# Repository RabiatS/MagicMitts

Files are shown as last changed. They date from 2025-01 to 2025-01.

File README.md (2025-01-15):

<!--
Name of your team's  project
-->
# Magic Mitts - Electromagnetic Haptic gloves for realistic VR interactions

<!--
List all of the members who developed the project and
link to each members respective GitHub profile
-->
Developed by: 
- [Rabiat Sadiq](https://github.com/rabiats) - `Computer Engineer / CS` - `University of Texas at San Antonio`
- [John Navarro ](https://github.com/rabiats) -`Electrical Engineer` - `University of Texas at San Antonio`
- [Juan Casillas](https://github.com/rabiats) - `Computer Engineer` - `University of Texas at San Antonio`
- [Blake Novosad](https://github.com/rabiats) - `Electrical Engineer` - `University of Texas at San Antonio`

## Description
<!--
Give a short description on what your project accomplishes and what tools is uses. In addition, you can drop screenshots directly into your README file to add them to your README. Take these from your presentations.
-->
The Smart VR Glove is an affordable innovation in virtual reality technology that offers users an immersive and realistic experience across standard VR systems.
It utilizes a novel electromagnetic braking system and haptic actuators to provide precise tactile feedback, simulating the sensation of touch and grasp in the virtual world. 
Enhanced by our own self-developed hardware driver, the glove’s flex-sensitive resistors offer superior finger-tracking accuracy.
This wireless, rechargeable battery-powered glove is designed to provide VR users with a more natural VR experience, setting a new benchmark for affordability, compatibility, and interactivity in virtual environments.



## Need for product 
Current virtual reality (VR) and augmented reality (AR) are
currently devoid of an affordable, immersive accessory that offers
haptic feedback and finger pullback functionality, leading to less
engaging user experience marked by inadequate dexterity and
prevalent compatibility issues. The few comprehensive solutions
available, like those from HaptX, command prices upwards of
$4,000, placing them beyond the reach of a broader audience.
This significant cost barrier impedes the universal development
and adoption of deeply immersive and personalized VR/AR
experiences



HatpX Glove



Air Compressor Backpack

## Flow charts
Hardware Flowchart



Software Flowchart



## Features
-  Electromagnetic braking system for simulated grasping resistance
- Integrated motion sensors for accurate hand/finger tracking
- Vibrating Actuators at fingertips for touch feedback
- Seamless connectivity with standard VR platforms
- Lightweight and portable design

## PCB Built from scratch

- Dual Rechargeable Battery System
- USB-C Port Power Compatibility
- Integrated Sensor Processing
- Wireless Communication Module
- Isolated Signal and Boost Converters
- Overpower Protection Circuit



Watch Video

https://github.com/user-attachments/assets/a56b95c6-07c2-43ef-859a-14ec5439370d

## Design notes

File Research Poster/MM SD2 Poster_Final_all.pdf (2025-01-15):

# Electromagnetic Haptic Gloves for Realistic VR Interaction

# Rabiat Sadiq, John Navarro, Juan Casillas, Blake Novosad

•- $
•Electromagnetic Strips -
•Flex Sensors -
•Haptic Actuators -
•Open glove software - NA

### Abstract

### Need for Product

The smart glove provides precise finger tracking via flex sensors, dynamic haptic feedback through strategically placed actuators, and a novel braking system for realistic resistive forces.

Current virtual reality (VR) and augmented reality (AR) are currently devoid of an affordable, immersive accessory that offers haptic feedback and finger pullback functionality, leading to less engaging user experience marked by inadequate dexterity and prevalent compatibility issues. The few comprehensive solutions available, like those from HaptX, command prices upwards of $4,000, placing them beyond the reach of a broader audience. This significant cost barrier impedes the universal development and adoption of deeply immersive and personalized VR/AR experiences.

## Product Description

### Hardware Flowchart

### Software Flowchart

### Project Budget

### Verification and Validation Testing

### Acknowledgements

The Smart VR Glove, an affordable innovation in virtual reality technology, offers users an immersive and realistic experience across the multiple VR systems currently available on the market. Its novel electromagnetic braking system and haptic actuators will provide precise tactile feedback, simulating the sensation of touch and grasp in the virtual world. Enhanced by AI-driven software, our flex sensitive resistors offer superior finger-tracking accuracy. This wireless, battery-powered glove is a commercially accessible solution designed to provide VR users with a more natural VR experience, setting a new benchmark for affordability, compatibility, and interactivity in virtual environments.

- Electromagnetic braking system for simulated grasping resistance
- Integrated motion sensors for accurate hand/finger tracking
- Vibrating Actuators at fingertips for touch feedback
- Seamless connectivity with standard VR platforms
- Lightweight and portable design
Figure 1: HatpX Glove | Figure 2: Air Compressor Backpack

Figure 3: Electromagnetic
Braking System | Figure 4: Finger Tracking Maps

Figure 5: Hardware Block Diagram

Figure 6: Software Block Diagram

The Magic Mitts team extends heartfelt gratitude to Ryan Saavedra the CEO
of Alt-Bionics, the UTSA Makerspace, LucasVR and our esteemed Professors for their invaluable technical guidance and support throughout our project journey. We also wish to express our sincere appreciation to the UTSA Makerspace, Student Success Center, and the entire faculty and staff of the UTSA ECE department for their generous provision of resources.

### Implementation and Integration

The verification and validation testing process included the Smart VR Glove’s core functions—resistance, haptics, tracking, connectivity, power, comfort, and durability—to ensure reliable performance. Rigorous testing and verification was crucial to meet quality standards, user satisfaction, and longterm durability for various VR applications.

Figure 3: Population of flexsensors on gloves

Figure 4:
Electromagnetic
braking system
ball bearing
module

Figure 5: Electro- magnetic braking full five finger module

Figure 6: Testing finger/hand tracking, grab detection, and haptics

Figure 7: Simulation testing

Table 2: Verification and Testing

Table 1: Budget

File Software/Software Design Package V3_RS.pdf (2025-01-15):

Smart Glove for VR by Magic Mitts

Team members: Rabiat Sadiq, Blake Novosad, John Navarro, Juan Casillas

Design Package V2 – 10/03/2024

Description: This document contains the details of the software planning in the project

Project Name: Smart Glove for VR.

Team Name: Magic Mitts

Team Members: Rabiat Sadiq, Blake Novosad, John Navarro, Juan Casillas

Instructor: August Allo & Johnathan Votion Ph.D

Team members: Rabiat Sadiq, Blake Novosad, John Navarro, Juan Casillas

Software Overview and Pseudo Code

The software component of our Smart Glove integrates multiple systems, including the ESP32 microcontroller, Unity environment, and electromagnetic braking, to deliver an immersive VR experience.
Pseudo code for Full Hand Control System with Electromagnetic Braking and ESP32 is as followed:

Initialization:

1. Start
- Setup ESP32 microcontroller
- Setup Power Pack (Dual 3.7V Battery Cells with Boost Converters)
- Initialize all 5 flex sensors connected to ESP32 GPIO
- Initialize the electromagnetic braking system with boost converters and MOSFETs
- Setup Serial Communication between ESP32 and Unity
- Initialize all finger joint transforms in Unity
- Initialize interactable objects in Unity with appropriate colliders

Main Control Loop in ESP32:

1. Read values from all 5 flex sensors (Thumb, Index, Middle, Ring, Pinky)
2. Map sensor values to bending angles for each finger
3. Send mapped angles to Unity via Serial in CSV format
4. Check for incoming commands from Unity:
- If command == "BRAKE": Activate corresponding electromagnetic brake
- Else if command == "RELEASE": Deactivate all electromagnetic brakes

Unity Main Loop:

1. Read sensor values from ESP32
2. Parse CSV data into individual finger joint angles
3. Apply Finger Movements:
- For each finger (Thumb, Index, Middle, Ring, Pinky), apply rotation to each joint (Knuckle, Middle, Tip) based on sensor data
4. Check for Object Interactions:
- If hand collides with object: Send "BRAKE" command to ESP32
- Else if hand moves away from the object: Send "RELEASE" command to ESP32

Electromagnetic Braking System Controlled by ESP32:

- If "BRAKE" command received, activate corresponding electromagnet, control MOSFETs, and maintain braking force until the "RELEASE" command.
- If "RELEASE" command received, deactivate all electromagnets and turn off boost converters to minimize power consumption.

Clean Up on Exit:

Team members: Rabiat Sadiq, Blake Novosad, John Navarro, Juan Casillas

- Close serial ports on ESP32 and Unity
- Deactivate all electromagnetic braking systems
- Power down boost converters

Code Details

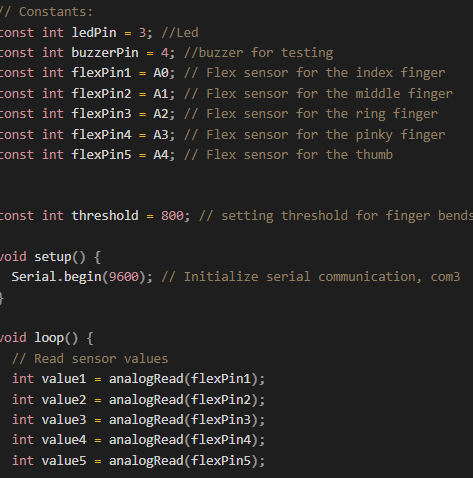
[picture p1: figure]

Figure 01: Arduino Setup

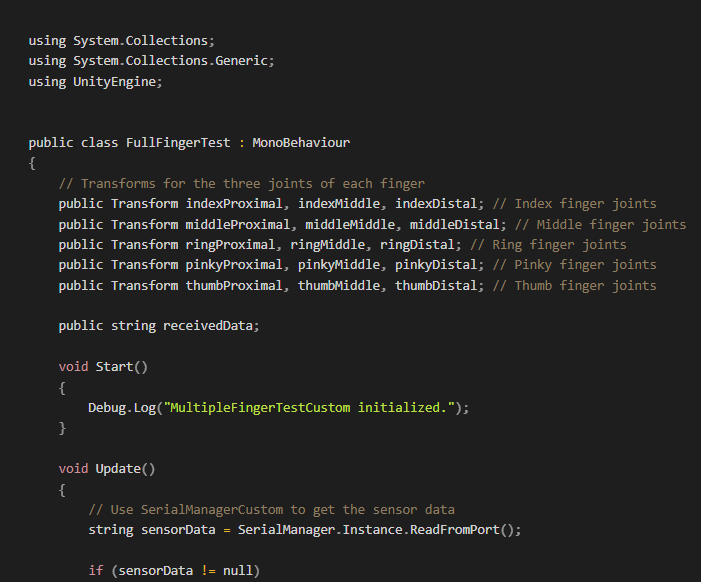
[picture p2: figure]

Figure 02: Unity Glove inputs

Team members: Rabiat Sadiq, Blake Novosad, John Navarro, Juan Casillas

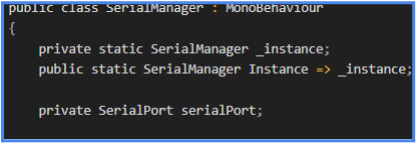
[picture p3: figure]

Figure 03: Unity serial Manager class

\

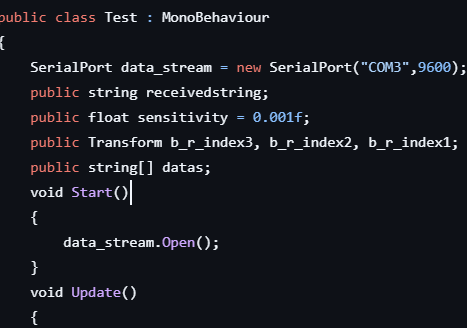
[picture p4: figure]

Figure 04: Starter code

Arduino Setup: (Figure 01)

- Functions:
- setup(): Initializes pin modes, serial communication at 9600 baud, and sets up pins for LED and buzzer.
- loop(): Reads flex sensor values, maps them to bending angles, and sends data via serial communication. Controls LED and buzzer based on flex sensor thresholds.

Unity C# Script:(Figure 02)

- Functions:
- Start():Initializes serial communication, references the SerialManager, and connects to the specified COM port to manage data exchange between Unity and the Arduino (ESP32).
- Update(): Reads incoming data from Arduino, parses it, and maps values to control virtual hand's finger joints.
- Map(): Utility function for mapping sensor values to rotation angles.
- OnApplicationQuit(): Ensures proper closure of the serial port.

Team members: Rabiat Sadiq, Blake Novosad, John Navarro, Juan Casillas

- OnCollisionEnter(): Detects collisions and sends feedback signals.
- SendBuzzCommand(): Sends a specific signal ("buzz") to the Arduino when an object is grabbed or touched, simulating haptic feedback or braking system.
- Software Code Progression:
- Single Finger: Initial setup for one flex sensor, controlling one finger in Unity.
- Multiple Fingers: Expanded to handle input from five flex sensors, controlling all fingers with realistic bending.
- Feedback Integration: Added buzzer feedback for interactions, simulating future electromagnetic braking or haptic feedback systems.
- Full Hand Tracking: Integrated with VR hand tracking, allowing for full hand locomotion, including collision detection and object interaction.

Modifications and Updates:

1. Serial Communication:(Figure 03)
- Integrated SerialManager in Unity for robust handling of input and output.
- Improved latency for more responsive control.
2. Finger Movement:
- Expanded from single to multi-finger tracking.
- Optimized for real-time input from all five flex sensors.
- Removed delays in Arduino code for real-time control.
3. Object Interaction and Collision Detection:
- Added collision detection and interaction logic.
- Introduced tags for interactable objects and colliders for each finger joint.
4. Hardware Interaction Feedback:
- Integrated external feedback (buzzing, LED activation) for collision detection.
- Adjusted control system for easy scaling with additional actuators.
5. VR Demo and Full-Glove Testing:
- Updated demo to display real-time interaction.
- Added new scenarios for comprehensive testing.

Modification Description:

- Modification from Starter Code:(Figure 04)
- The code expanded from a single-finger setup to handle five fingers, with sensor values adapted for flex sensors and smoothed for realistic joint movement. Integration with Oculus OVR rig and 3D hand models enabled lifelike virtual hand manipulation, and colliders ensure proper object interaction. Added collision detection and feedback, triggering signals like the buzzer when objects are touched. SerialManager was implemented for efficient serial communication, ensuring smooth data handling between hardware and Unity.

Note: Full code has been attached to the Design Package V2.

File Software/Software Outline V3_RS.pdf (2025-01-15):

Smart Glove for VR by Magic Mitts

Team members: Rabiat Sadiq, Blake Novosad, John Navarro, Juan Casillas

Design Package V2 – 10/31/2024

Description: This document contains the details of the software planning in the project, The software outline description of files, functions and variables, and modifications

Project Name: Smart Glove for VR.

Team Name: Magic Mitts

Team Members: Rabiat Sadiq, Blake Novosad, John Navarro, Juan Casillas

Instructor: August Allo & Johnathan Votion Ph.D

Team members: Rabiat Sadiq, Blake Novosad, John Navarro, Juan Casillas

Description of files
These are the description of each software files:
1. Unity_SerialManager.cs: This handles the com port connections and manages the command sending and data receiving
2. Full_gloves.ino: This is the main ESP32 control scripts, it handles the flex sensor reading and serial communication, the haptics and brake system control, it has the constants for the pins and thresholds.
3. GrabDetector.cs: This integrated with oculus SDK HandGrabInteractable, it detects and processes grab type and manages the active grabbing fingers, with a real time GUI debug info display.
4. FullFingeTtest.cs2: This file Processes the sensor data for all five fingers and maps the flex sensor values to finger rotations, this also allows for real time finger joint control
5. InteractionTest.cs: This file handles Collision detection and feedback
6. Output_Buzz_Test.cs: This file is to test sending output from unity - Without instance'

Description of functions and variables
These are the description of each key functions and variables:

SerialManager Class:
- SendCommand(): Sends formatted string commands to ESP32 through serial port with error handling
- ReadFromPort(): Reads and returns incoming CSV data from ESP32 through serial port
- SerialPort: Main COM port handler that manages 9600 baud rate connection with ESP32

GrabDetector Class:
- HandleGrabStart(): Initiates grab detection process and activates appropriate finger brakes based on grab type
- UpdateGrabbingFingers(): Monitors and updates which fingers are actively grabbing, adjusting brakes accordingly
- HandleGrabEnd(): Releases all brakes and resets grab state when object is released
- ActivateFingersWithFeedback(): Activates haptic feedback and brakes for specific fingers during grab

Team members: Rabiat Sadiq, Blake Novosad, John Navarro, Juan Casillas

- ReleaseFingersWithFeedback(): Releases brakes and haptic feedback when fingers stop grabbing
- GetActiveFingerNames(): Returns a string list of currently active grabbing fingers for debugging
- OnGUI(): Displays real-time debugging information about grab states and active fingers

FullFingerTest Class:
- ProcessSensorData(): Parses incoming ESP32 sensor data and converts to finger angles
- ApplyFingerRotations(): Applies calculated rotations to virtual finger joints based on sensor data
- Transform[] fingerJoints: Array storing Unity transform references for each finger joint
- float[] sensorValues: Array storing current flex sensor values from ESP32

Description of Modification:

- Modification from Starter Code:
- The code expanded from a single-finger setup to handle five fingers, with sensor values adapted for flex sensors and smoothed for realistic joint movement. Integration with Oculus OVR rig and 3D hand models enabled lifelike virtual hand manipulation, and colliders ensure proper object interaction. Added collision detection and feedback, triggering signals like the buzzer when objects are touched. SerialManager was implemented for efficient serial communication, ensuring smooth data handling between hardware and Unity.

Note: Full code has been attached to the Design Package V3.

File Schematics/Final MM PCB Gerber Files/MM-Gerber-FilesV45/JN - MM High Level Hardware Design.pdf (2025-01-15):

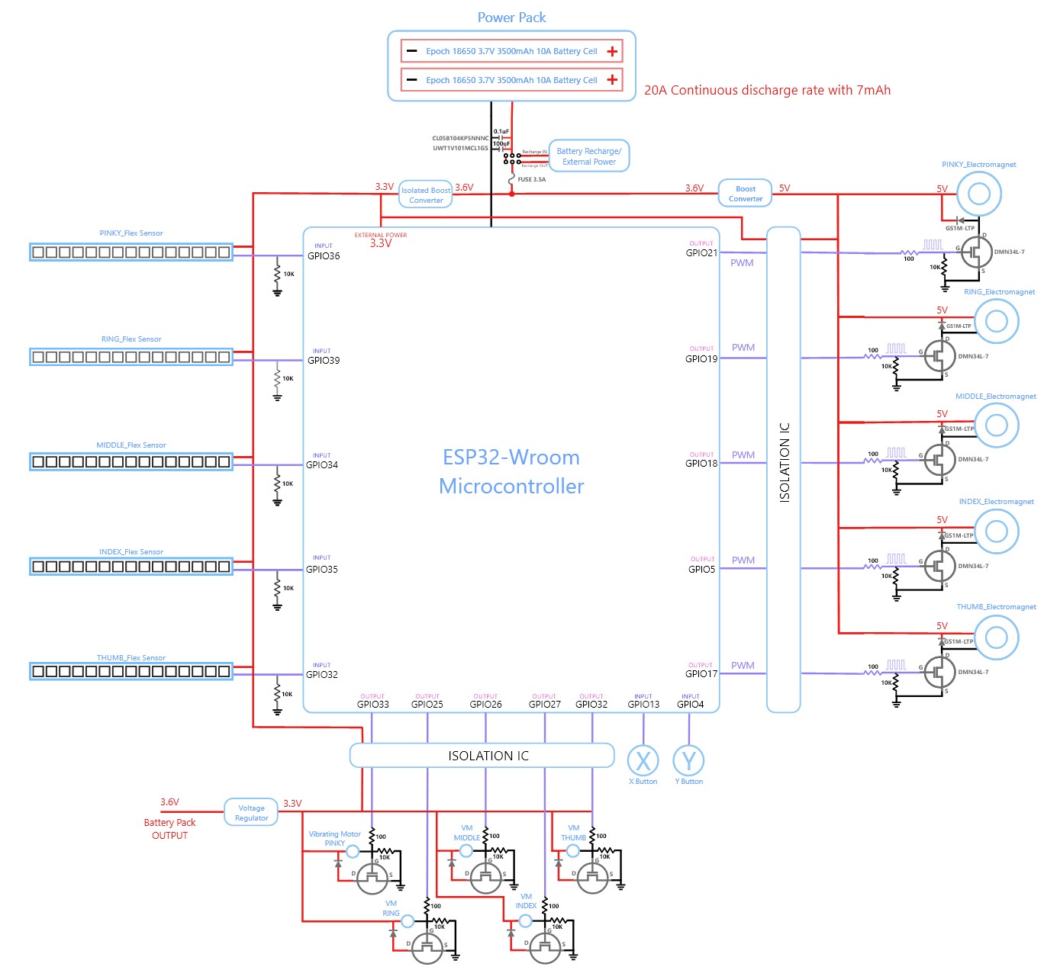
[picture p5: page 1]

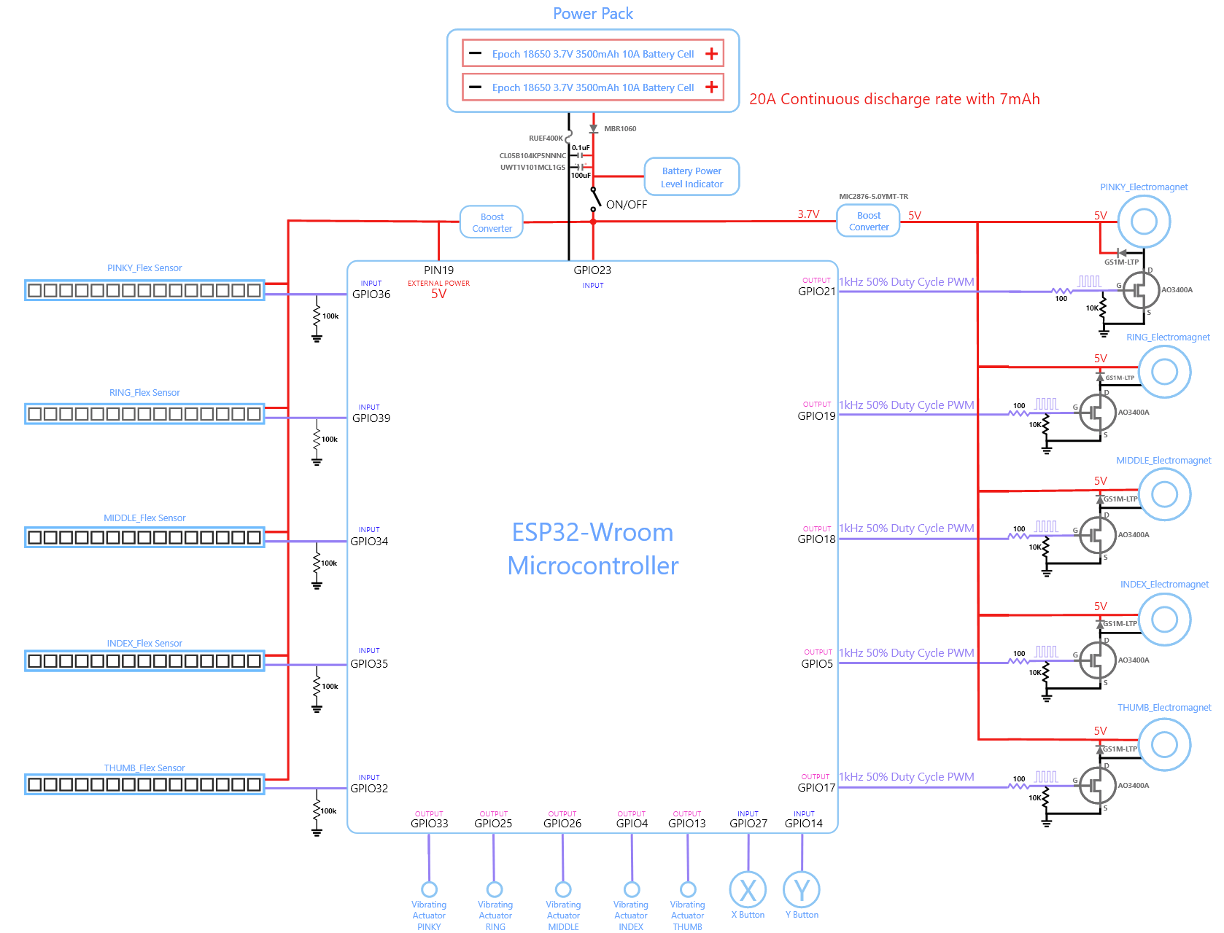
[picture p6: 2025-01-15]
Schematics/JN_Magic Mitts Schematic Proto A High Level Design.png

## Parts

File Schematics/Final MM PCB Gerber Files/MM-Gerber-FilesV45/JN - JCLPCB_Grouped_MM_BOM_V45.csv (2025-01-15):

Comment | Designator | Footprint
150060SS75000 | LED1, LED2, LED3, LED4, LED5, LED6, LED7, LED8, LED9, LED10, LED15 | 150060SS75000
150060VS75000 | D1 | 150060VS75000
150080BS75000 | D2 | 150080BS75000
61300211121 | J1, J2, J3, J4, J5, J6, J7, J8, J9, J10, J11, J12, J13, J14, J15, J16, J17, J18, J19, J20, J21, J22 | 61300211121
61300311121 | J26, J27 | 61300311121
61300411121 | J23 | 61300411121
BQ25895RTWR | U3 | BQ25895RTWR
C0402C473K3RECTU | C24 | C0402C473K3RECTU
CL05B104KP5NNNC | C2, C30, C31, C32, C33, C34 | CL05B104KP5NNNC
CL10A475KP8NNNC | C28, C36 | CL10A475KP8NNNC
CL10B105KP8NNNC | C23, C35 | CL10B105KP8NNNC
CL21A106KOQNNNE | C3, C4, C5, C6, C7, C8, C21, C25, C26, C27 | CL21A106KOQNNNE
CL31A226KPHNNNE | C22, C37, C38 | CL31A226KPHNNNE
DMN3404L-7 | MOSFET1, MOSFET2, MOSFET3, MOSFET4, MOSFET5, MOSFET6, MOSFET7, MOSFET8, MOSFET9, MOSFET10 | DMN3404L-7
ERJ-8ENF1000V | R6, R10, R14, R21, R27, R34, R37, R40, R43, R46 | ERJ-8ENF1000V
ESP32-DEVKITC-32E | U1 | ESP32-DEVKITC-32E
GS1M-LTP | CR2, CR3, CR4, CR5, CR6, CR7, CR8, CR9, CR10, CR11 | GS1M-LTP
ISO7760FDWR | U2, U5 | ISO7760FDWR
MF-NSML350/12-2 | F1 | MF-NSML350/12-2
MIC2876-5.0YMT-TR | U4 | MIC2876-5.0YMT-TR
NR6028T2R2N | L8 | NR6028T2R2N
PTS636SL43SMTRLFS | SW1 | PTS636SL43SMTRLFS
RMCF0402FT130R | R60 | RMCF0402FT130R
RMCF1206FT100K | R68 | RMCF1206FT100K
RMCF1206FT10K0 | R5, R9, R13, R20, R25, R28, R29, R30, R31, R32, R33, R36, R39, R42, R45, R62, R63 | RMCF1206FT10K0
RMCF1206JT2K20 | R61 | RMCF1206JT2K20
RMCF1206JT330R | R15, R16, R17, R22, R26, R35, R38, R41, R44, R47, R56, R57, R58, R59 | RMCF1206JT330R
RSH2-3.33.3S/H3 | PS1 | RSH2-3.33.3S/H3
RT1206BRD071ML | R67 | RT1206BRD071ML
SC189ZSKTRT | U13 | SC189ZSKTRT
SPM6530T-1R5M100 | L9 | SPM6530T-1R5M100
SRP4020TA-1R0M | L7 | SRP4020TA-1R0M
UWT1V101MCL1GS | C1 | UWT1V101MCL1GS

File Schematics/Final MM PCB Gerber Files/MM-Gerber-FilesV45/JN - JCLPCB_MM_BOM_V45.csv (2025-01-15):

Comment | Designator | Footprint
100uF | C1 | UWT1V101MCL1GSPCAP_6.3X7.7-ELECT_NCA-L
0.1uF | C2 | CL05B104KP5NNNCCAP_CL05_SAM-L
10uF | C3 | CL21A106KOQNNNECAP_CL21_SAM-L
10uF | C4 | CL21A106KOQNNNECAP_CL21_SAM-L
10uF | C5 | CL21A106KOQNNNECAP_CL21_SAM-L
10uF | C6 | CL21A106KOQNNNECAP_CL21_SAM-L
10uF | C7 | CL21A106KOQNNNECAP_CL21_SAM-L
10uF | C8 | CL21A106KOQNNNECAP_CL21_SAM-L
10uF | C21 | CL21A106KOQNNNECAP_CL21_SAM-L
22uF | C22 | CL31A226KPHNNNECAP_CL31_SAM-L
1uF | C23 | CL10B105KP8NNNCCAP_CL10_SAM-L
47nF | C24 | C0402C473K3RECTUCAPC10555_55N_KEM-L
10uF | C25 | CL21A106KOQNNNECAP_CL21_SAM-L
10uF | C26 | CL21A106KOQNNNECAP_CL21_SAM-L
10uF | C27 | CL21A106KOQNNNECAP_CL21_SAM-L
4.7uF | C28 | CL10A475KP8NNNCAP_CL10_SAM-L
0.1uF | C30 | CL05B104KP5NNNCCAP_CL05_SAM-L
0.1uF | C31 | CL05B104KP5NNNCCAP_CL05_SAM-L
0.1uF | C32 | CL05B104KP5NNNCCAP_CL05_SAM-L
0.1uF | C33 | CL05B104KP5NNNCCAP_CL05_SAM-L
0.1uF | C34 | CL05B104KP5NNNCCAP_CL05_SAM-L
1uF | C35 | CL10B105KP8NNNCCAP_CL10_SAM-L
4.7uF | C36 | CL10A475KP8NNNCAP_CL10_SAM-L
22uF | C37 | CL31A226KPHNNNECAP_CL31_SAM-L
22uF | C38 | CL31A226KPHNNNECAP_CL31_SAM-L
EL_P_D | CR2 | GS1M-LTPCR_GS1M-LTP_MCE-L
EL_R_D | CR3 | GS1M-LTPCR_GS1M-LTP_MCE-L
EL_M_D | CR4 | GS1M-LTPCR_GS1M-LTP_MCE-L
EL_I_D | CR5 | GS1M-LTPCR_GS1M-LTP_MCE-L
EL_T_D | CR6 | GS1M-LTPCR_GS1M-LTP_MCE-L
VM_P_D | CR7 | GS1M-LTPCR_GS1M-LTP_MCE-L
VM_R_D | CR8 | GS1M-LTPCR_GS1M-LTP_MCE-L
VM_M_D | CR9 | GS1M-LTPCR_GS1M-LTP_MCE-L
VM_I_D | CR10 | GS1M-LTPCR_GS1M-LTP_MCE-L
VM_T_D | CR11 | GS1M-LTPCR_GS1M-LTP_MCE-L
PWR_ST_LED | D1 | WL-SMCW_0603
CON_ST_LED | D2 | WL-SMCW_0805
MF-NSML350_12-2 | F1 | MF-NSML350_12-2
BTR_IN | J1 | 61300211121CONN_61300211121_WRE
EL_P | J2 | 61300211121CONN_61300211121_WRE
EL_R | J3 | 61300211121CONN_61300211121_WRE
EL_M | J4 | 61300211121CONN_61300211121_WRE
EL_I | J5 | 61300211121CONN_61300211121_WRE
EL_T | J6 | 61300211121CONN_61300211121_WRE
FX_P | J7 | 61300211121CONN_61300211121_WRE
FX_R | J8 | 61300211121CONN_61300211121_WRE
FX_M | J9 | 61300211121CONN_61300211121_WRE
FX_I | J10 | 61300211121CONN_61300211121_WRE
FX_T | J11 | 61300211121CONN_61300211121_WRE
VM_P | J12 | 61300211121CONN_61300211121_WRE
VM_R | J13 | 61300211121CONN_61300211121_WRE
VM_M | J14 | 61300211121CONN_61300211121_WRE
VM_I | J15 | 61300211121CONN_61300211121_WRE
VM_T | J16 | 61300211121CONN_61300211121_WRE
BTN_X | J17 | 61300211121CONN_61300211121_WRE
BTN_Y | J18 | 61300211121CONN_61300211121_WRE
BTN_PWR | J19 | 61300211121CONN_61300211121_WRE
BTN_ACTN | J20 | 61300211121CONN_61300211121_WRE
CONNECTION_STATUS | J21 | 61300211121CONN_61300211121_WRE
POWER_STATUS | J22 | 61300211121CONN_61300211121_WRE
USBC | J23 | 6130XX11121_61300411121
BTR_IN | J26 | 6130XX11121_61300311121
BTR_OUT | J27 | 6130XX11121_61300311121
1uH | L7 | SRP4020TA-1R0MIND_SRP4020TA-1R0M_BRN-L
2.2uH | L8 | NR6028T2R2NIND_TAIYO_NR6028_TAY
1.5uH | L9 | SPM6530T-1R5M100
EL_P_LED | LED1 | 150060SS75000LED_WL-SMCW-SMT_0603_WRE-L
EL_R_LED | LED2 | 150060SS75000LED_WL-SMCW-SMT_0603_WRE-L
EL_M_LED | LED3 | 150060SS75000LED_WL-SMCW-SMT_0603_WRE-L
EL_I_LED | LED4 | 150060SS75000LED_WL-SMCW-SMT_0603_WRE-L
EL_T_LED | LED5 | 150060SS75000LED_WL-SMCW-SMT_0603_WRE-L
VM_P_LED | LED6 | 150060SS75000LED_WL-SMCW-SMT_0603_WRE-L
VM_R_LED | LED7 | 150060SS75000LED_WL-SMCW-SMT_0603_WRE-L
VM_M_LED | LED8 | 150060SS75000LED_WL-SMCW-SMT_0603_WRE-L
VM_I_LED | LED9 | 150060SS75000LED_WL-SMCW-SMT_0603_WRE-L
VM_T_LED | LED10 | 150060SS75000LED_WL-SMCW-SMT_0603_WRE-L
CHR_LED | LED15 | 150060SS75000LED_WL-SMCW-SMT_0603_WRE-L
EL_P_MF | MOSFET1 | DMN3404L-7SOT23_DIO-L
EL_I_MS | MOSFET2 | DMN3404L-7SOT23_DIO-L
EL_R_MS | MOSFET3 | DMN3404L-7SOT23_DIO-L
EL_M_MS | MOSFET4 | DMN3404L-7SOT23_DIO-L
EL_T_MS | MOSFET5 | DMN3404L-7SOT23_DIO-L
VM_P_MF | MOSFET6 | DMN3404L-7SOT23_DIO-L
VM_R_MF | MOSFET7 | DMN3404L-7SOT23_DIO-L
VM_M_MF | MOSFET8 | DMN3404L-7SOT23_DIO-L
VM_T_MF | MOSFET9 | DMN3404L-7SOT23_DIO-L
VM_I_MF | MOSFET10 | DMN3404L-7SOT23_DIO-L
RSH2-3.33.3S_H3 | PS1 | RSH2-3.33.3S_H3
10k | R5 | RMCF1206FT10K0STA_RMCF1206_STP-L
100 | R6 | ERJ-8ENF1000VRC1206N_PAN-L
10k | R9 | RMCF1206FT10K0STA_RMCF1206_STP-L
100 | R10 | ERJ-8ENF1000VRC1206N_PAN-L
10k | R13 | RMCF1206FT10K0STA_RMCF1206_STP-L
100 | R14 | ERJ-8ENF1000VRC1206N_PAN-L
330 | R15 | RMCF1206JT330RSTA_RMCF1206_STP-L
330 | R16 | RMCF1206JT330RSTA_RMCF1206_STP-L
330 | R17 | RMCF1206JT330RSTA_RMCF1206_STP-L
10k | R20 | RMCF1206FT10K0STA_RMCF1206_STP-L
100 | R21 | ERJ-8ENF1000VRC1206N_PAN-L
330 | R22 | RMCF1206JT330RSTA_RMCF1206_STP-L
10k | R25 | RMCF1206FT10K0STA_RMCF1206_STP-L
330 | R26 | RMCF1206JT330RSTA_RMCF1206_STP-L
100 | R27 | ERJ-8ENF1000VRC1206N_PAN-L
10k | R28 | RMCF1206FT10K0STA_RMCF1206_STP-L
10k | R29 | RMCF1206FT10K0STA_RMCF1206_STP-L
10k | R30 | RMCF1206FT10K0STA_RMCF1206_STP-L
10k | R31 | RMCF1206FT10K0STA_RMCF1206_STP-L
10k | R32 | RMCF1206FT10K0STA_RMCF1206_STP-L
10k | R33 | RMCF1206FT10K0STA_RMCF1206_STP-L
100 | R34 | ERJ-8ENF1000VRC1206N_PAN-L
330 | R35 | RMCF1206JT330RSTA_RMCF1206_STP-L
10k | R36 | RMCF1206FT10K0STA_RMCF1206_STP-L
100 | R37 | ERJ-8ENF1000VRC1206N_PAN-L
330 | R38 | RMCF1206JT330RSTA_RMCF1206_STP-L
10k | R39 | RMCF1206FT10K0STA_RMCF1206_STP-L
100 | R40 | ERJ-8ENF1000VRC1206N_PAN-L
330 | R41 | RMCF1206JT330RSTA_RMCF1206_STP-L
10k | R42 | RMCF1206FT10K0STA_RMCF1206_STP-L
100 | R43 | ERJ-8ENF1000VRC1206N_PAN-L
330 | R44 | RMCF1206JT330RSTA_RMCF1206_STP-L
10k | R45 | RMCF1206FT10K0STA_RMCF1206_STP-L
100 | R46 | ERJ-8ENF1000VRC1206N_PAN-L
330 | R47 | RMCF1206JT330RSTA_RMCF1206_STP-L
330 | R56 | RMCF1206JT330RSTA_RMCF1206_STP-L
330 | R57 | RMCF1206JT330RSTA_RMCF1206_STP-L
330 | R58 | RMCF1206JT330RSTA_RMCF1206_STP-L
330 | R59 | RMCF1206JT330RSTA_RMCF1206_STP-L
130 | R60 | RMCF0402FT130RSTA_RMCF0402_STP-L
2.2k | R61 | RMCF1206JT2K20STA_RMCF1206_STP-L
10k | R62 | RMCF1206FT10K0STA_RMCF1206_STP-L
10k | R63 | RMCF1206FT10K0STA_RMCF1206_STP-L
1M | R67 | RT1206BRD071MLRC1206N_YAG-L
100k | R68 | RMCF1206FT100KSTA_RMCF1206_STP-L
CHR_RBT | SW1 | PTS636SL43SMTRLFSSW_PTS636S-J_CNK
ESP32-DEVKITC-32E | U1 | ESP32-DEVKITC-32E
ISO7760FDWRDW0016B_HV | U2 | ISO7760FDWRDW0016B_HV
BQ25895RTWR | U3 | BQ25895RTWR
MIC2876 | U4 | MIC2876-5.0YMT-TRUDFN8_2X2_MCH-L
ISO7760FDWRDW0016B_HV | U5 | ISO7760FDWRDW0016B_HV
VM_PWR | U13 | SC189ZSKTRTSOT23-5-SC189_SEM-L

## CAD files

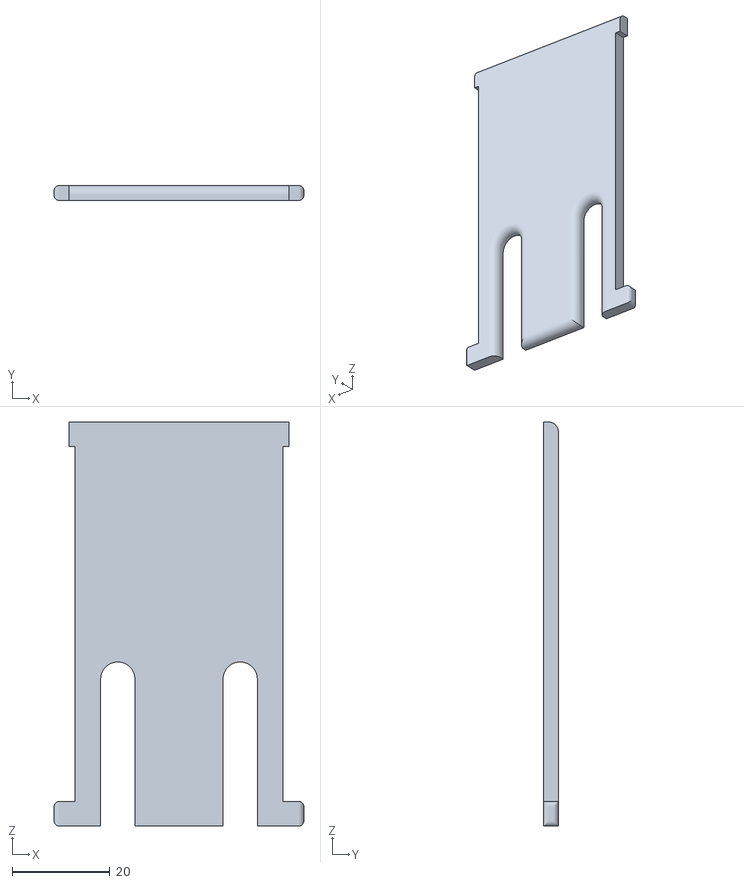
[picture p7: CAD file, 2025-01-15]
CAD Drawing/BN - Battery Pack/BN - BP Proto A/BN - BP_LID A.STL
51.0 x 3.00 x 82.5

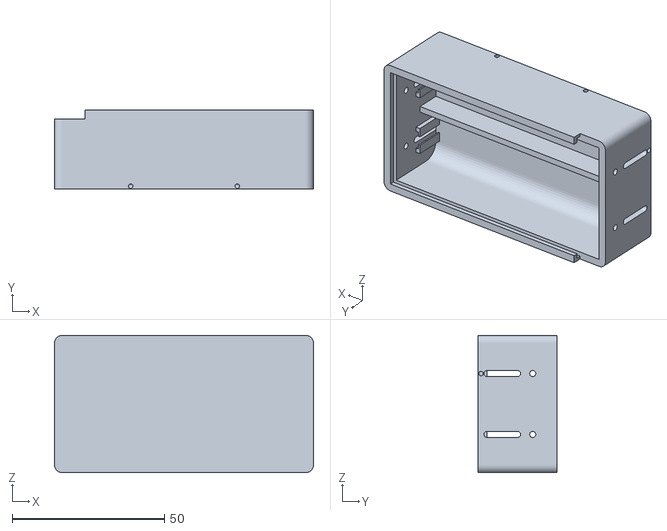
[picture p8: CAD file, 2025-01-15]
CAD Drawing/BN - Battery Pack/BN - BP Proto B/BN - BP_BOTTOM B.STL
85.0 x 26.0 x 45.0

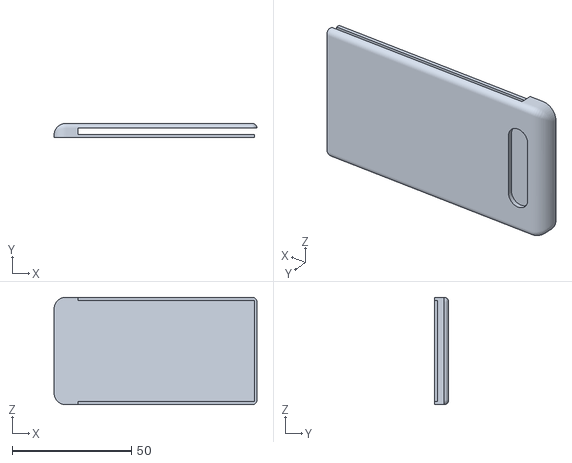
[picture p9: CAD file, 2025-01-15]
CAD Drawing/BN - Battery Pack/BN - BP Proto C/BN - TOP.STL
85.0 x 6.00 x 45.0

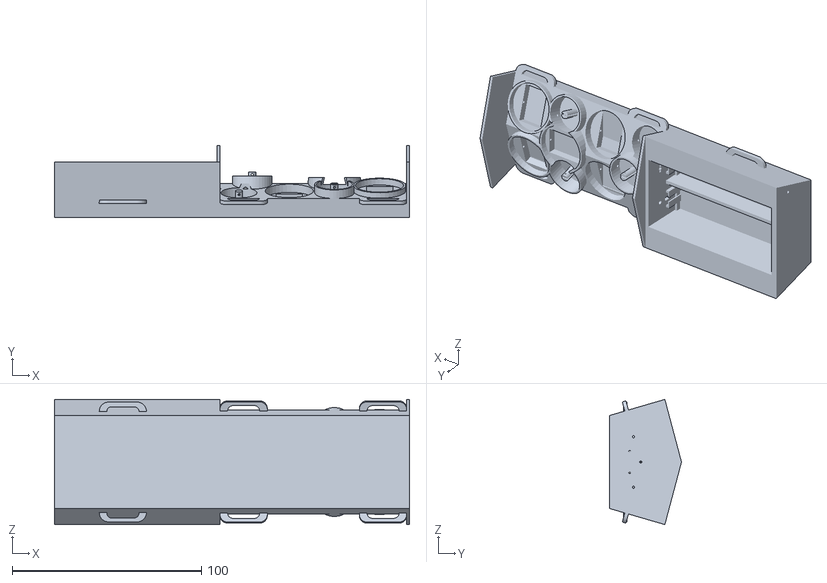
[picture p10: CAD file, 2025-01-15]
CAD Drawing/BN - Combination Pack/combo.STL
187.7 x 38.1 x 66.2

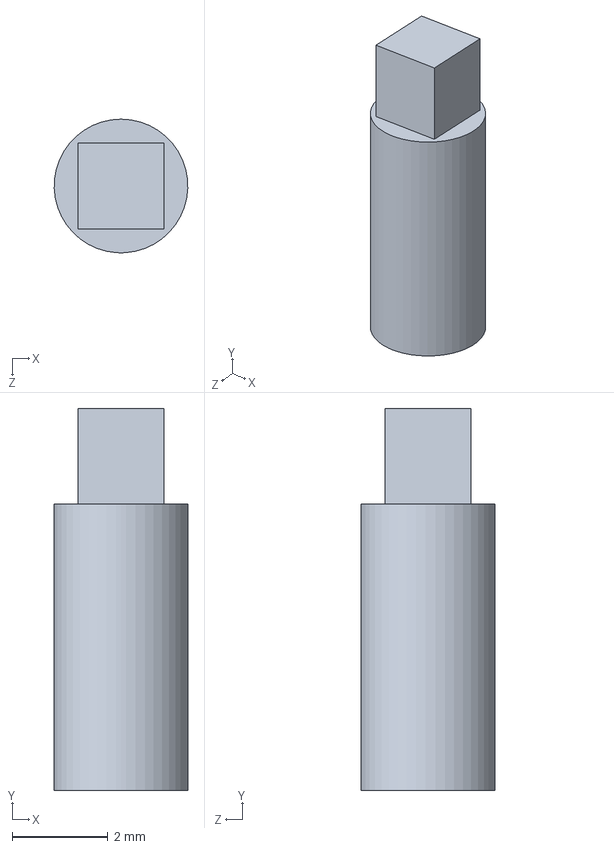
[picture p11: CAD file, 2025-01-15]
CAD Drawing/JN - Ball Bearing Testing/JN - BB Testing 1/JN - Bearing Pole 1.4R.SLDPRT
2.80 x 8.00 x 2.80 mm

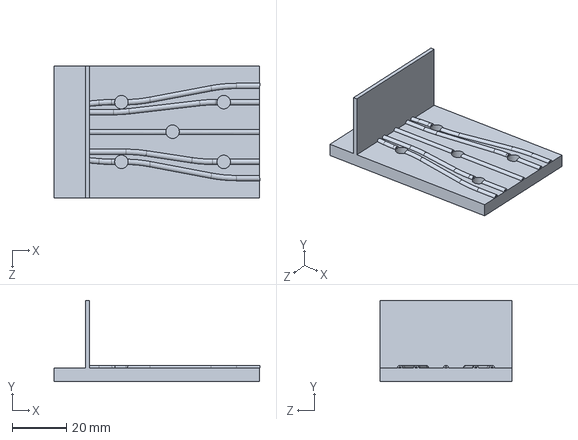
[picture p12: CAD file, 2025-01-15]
CAD Drawing/JN - Control Center/CC Proto A/JN - Bottom String Circuit.SLDPRT
76.1 x 30.0 x 48.7 mm

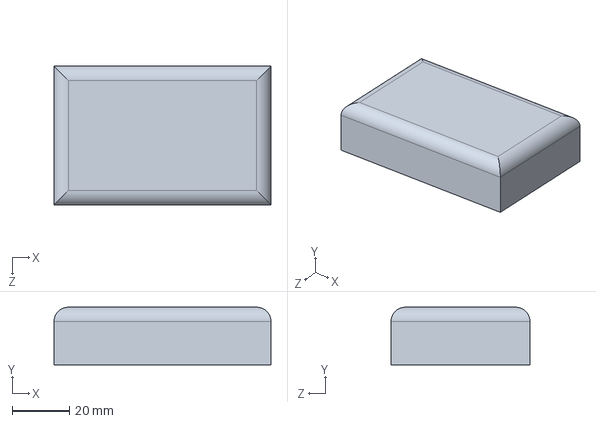
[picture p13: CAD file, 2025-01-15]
CAD Drawing/JN - Control Center/CC Proto B/JN - L4B Battery Housing.SLDPRT
76.0 x 20.2 x 48.7 mm

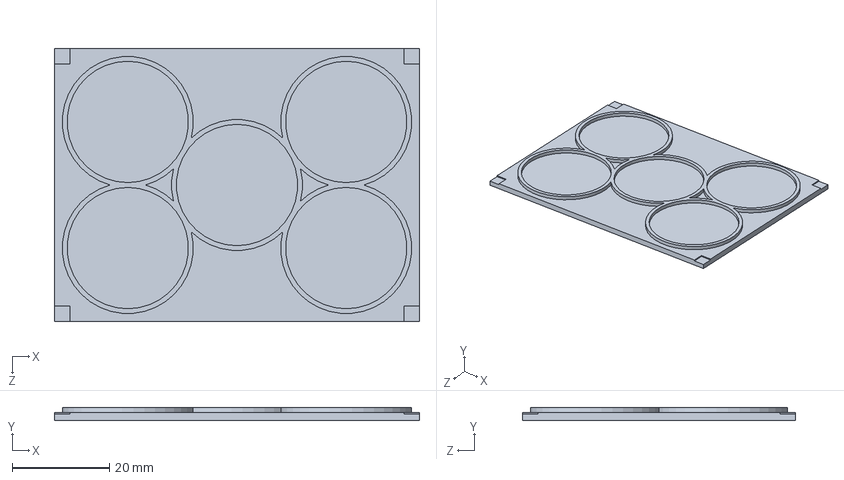
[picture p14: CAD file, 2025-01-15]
CAD Drawing/JN - Control Center/CC Proto C/JN - L2C Electromagnetic Cap.SLDPRT
75.2 x 2.60 x 56.2 mm

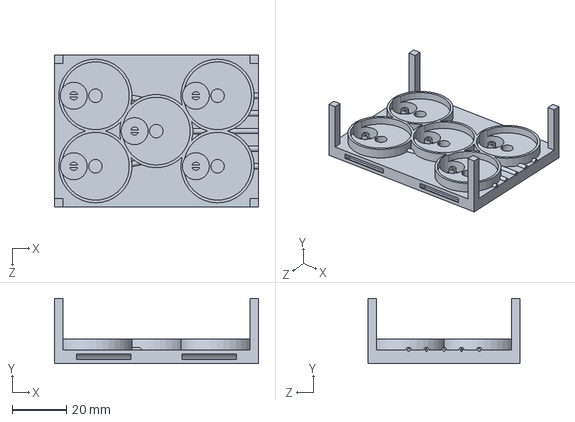
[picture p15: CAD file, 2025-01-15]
CAD Drawing/JN - Control Center/CC Proto D/JN - L1C Bottom String Circuit.SLDPRT
75.2 x 24.0 x 56.2 mm

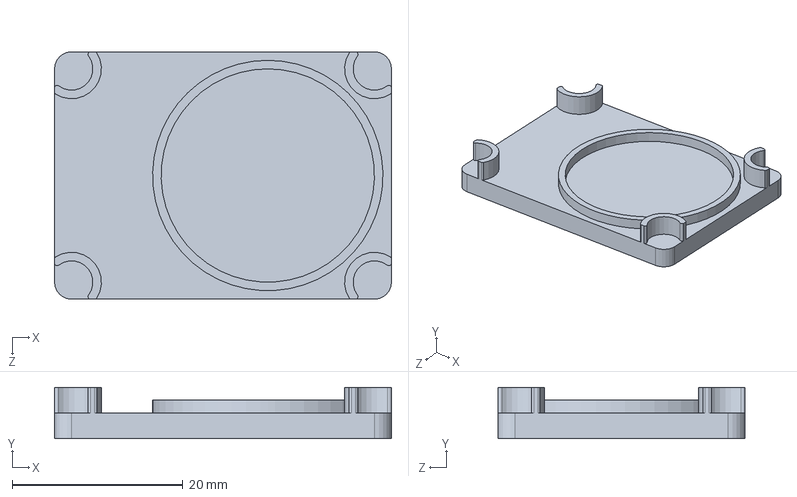
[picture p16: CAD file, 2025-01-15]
CAD Drawing/JN - Control Center/CC Proto E/JN - TP L2E Electromagnet Cap.SLDPRT
39.5 x 6.00 x 29.0 mm

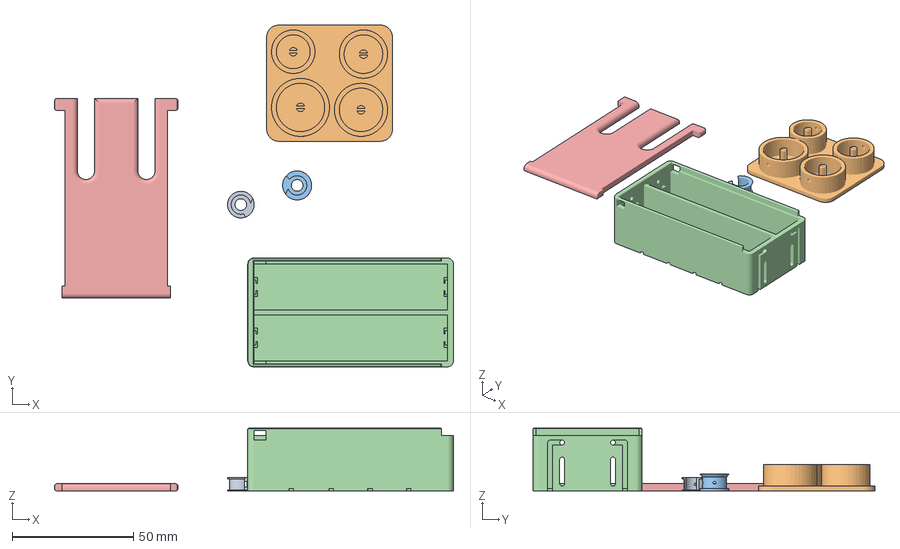
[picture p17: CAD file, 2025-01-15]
CAD Drawing/JN - Control Center/CC Proto F/JN - LF Badge Reel Component.3mf
164.8 x 141.2 x 26.0 mm
LF Badge Reel Component.STL
Reel Housing T1.STL
S1 Reel T1.STL
Battery_TOP.STL
TOP.STL

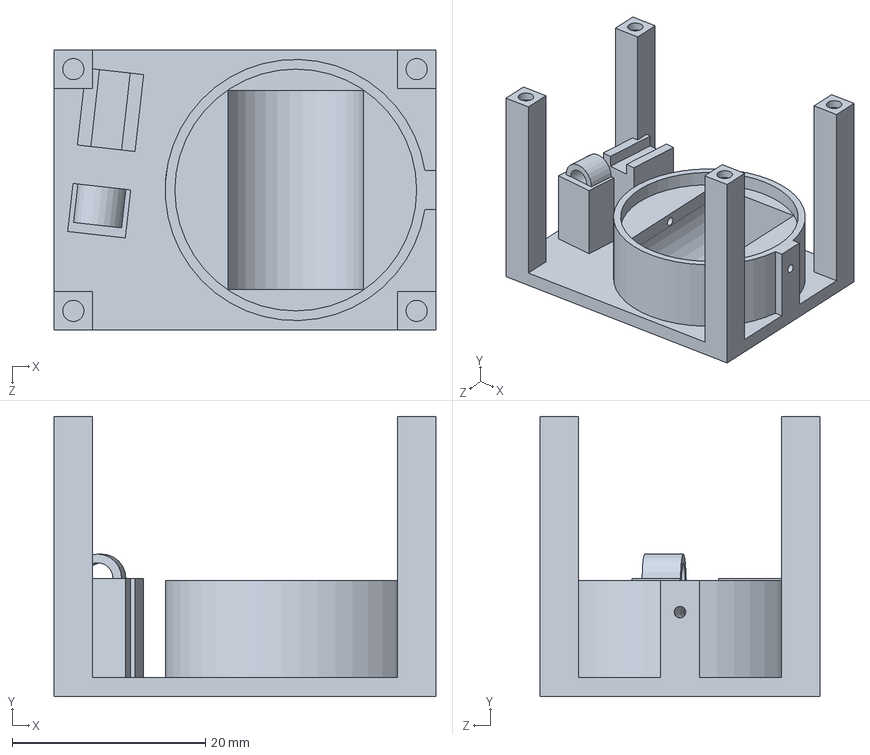
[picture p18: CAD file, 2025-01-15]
CAD Drawing/JN - Control Center/CC Proto G/JN - TP L1G Electromagnetic and String Routing.SLDPRT
39.5 x 29.0 x 29.0 mm

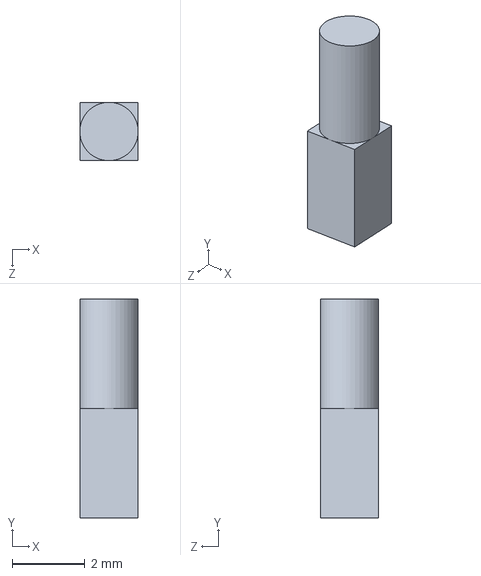
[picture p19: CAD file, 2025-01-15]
CAD Drawing/JN - Control Center/CC Proto H/JN - TP L1H Badge Reel Clip.SLDPRT
1.60 x 6.00 x 1.60 mm

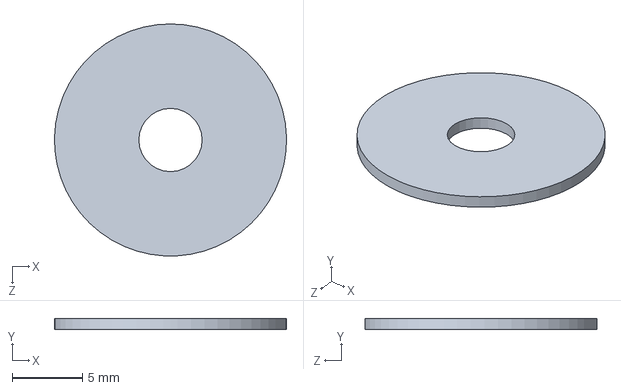
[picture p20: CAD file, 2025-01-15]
CAD Drawing/JN - Control Center/CC Proto J/JN - L1J Reel Cap.SLDPRT
16.5 x 0.8 x 16.5 mm

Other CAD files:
CAD Drawing/JN - Control Center/CC Proto K/JN - L1K Electromagnetic and String Housing.SLDPRT
CAD Drawing/JN - Control Center/CC Proto L/JN - L1L Electromagnetic and String Housing.SLDPRT
CAD Drawing/JN - Control Center/CC Proto M/JN - L1M Electromagnetic and String Housing.SLDPRT
CAD Drawing/JN - Finger Caps and Tracks/JN - FCT Proto A/JN - Top Finger Cap - TFC-A.SLDPRT
CAD Drawing/BN - Battery Pack/BN - BP Proto A/BN - BP_BOTTOM A.STL
CAD Drawing/BN - Battery Pack/BN - BP Proto B/BN - BP_LID B.STL
CAD Drawing/BN - Battery Pack/BN - BP Proto C/BN - Battery_BOTTOM.STL
CAD Drawing/JN - Ball Bearing Testing/JN - BB Testing 1/JN - Bearing Pole 1.4R.STL
CAD Drawing/JN - Ball Bearing Testing/JN - BB Testing 1/JN - Bearing Pole 1.5R.SLDPRT
CAD Drawing/JN - Ball Bearing Testing/JN - BB Testing 1/JN - Bearing Pole 1.5R.STL
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

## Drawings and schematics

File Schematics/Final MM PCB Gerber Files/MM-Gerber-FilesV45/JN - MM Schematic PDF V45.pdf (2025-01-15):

100uF | GND

# 1uF GND

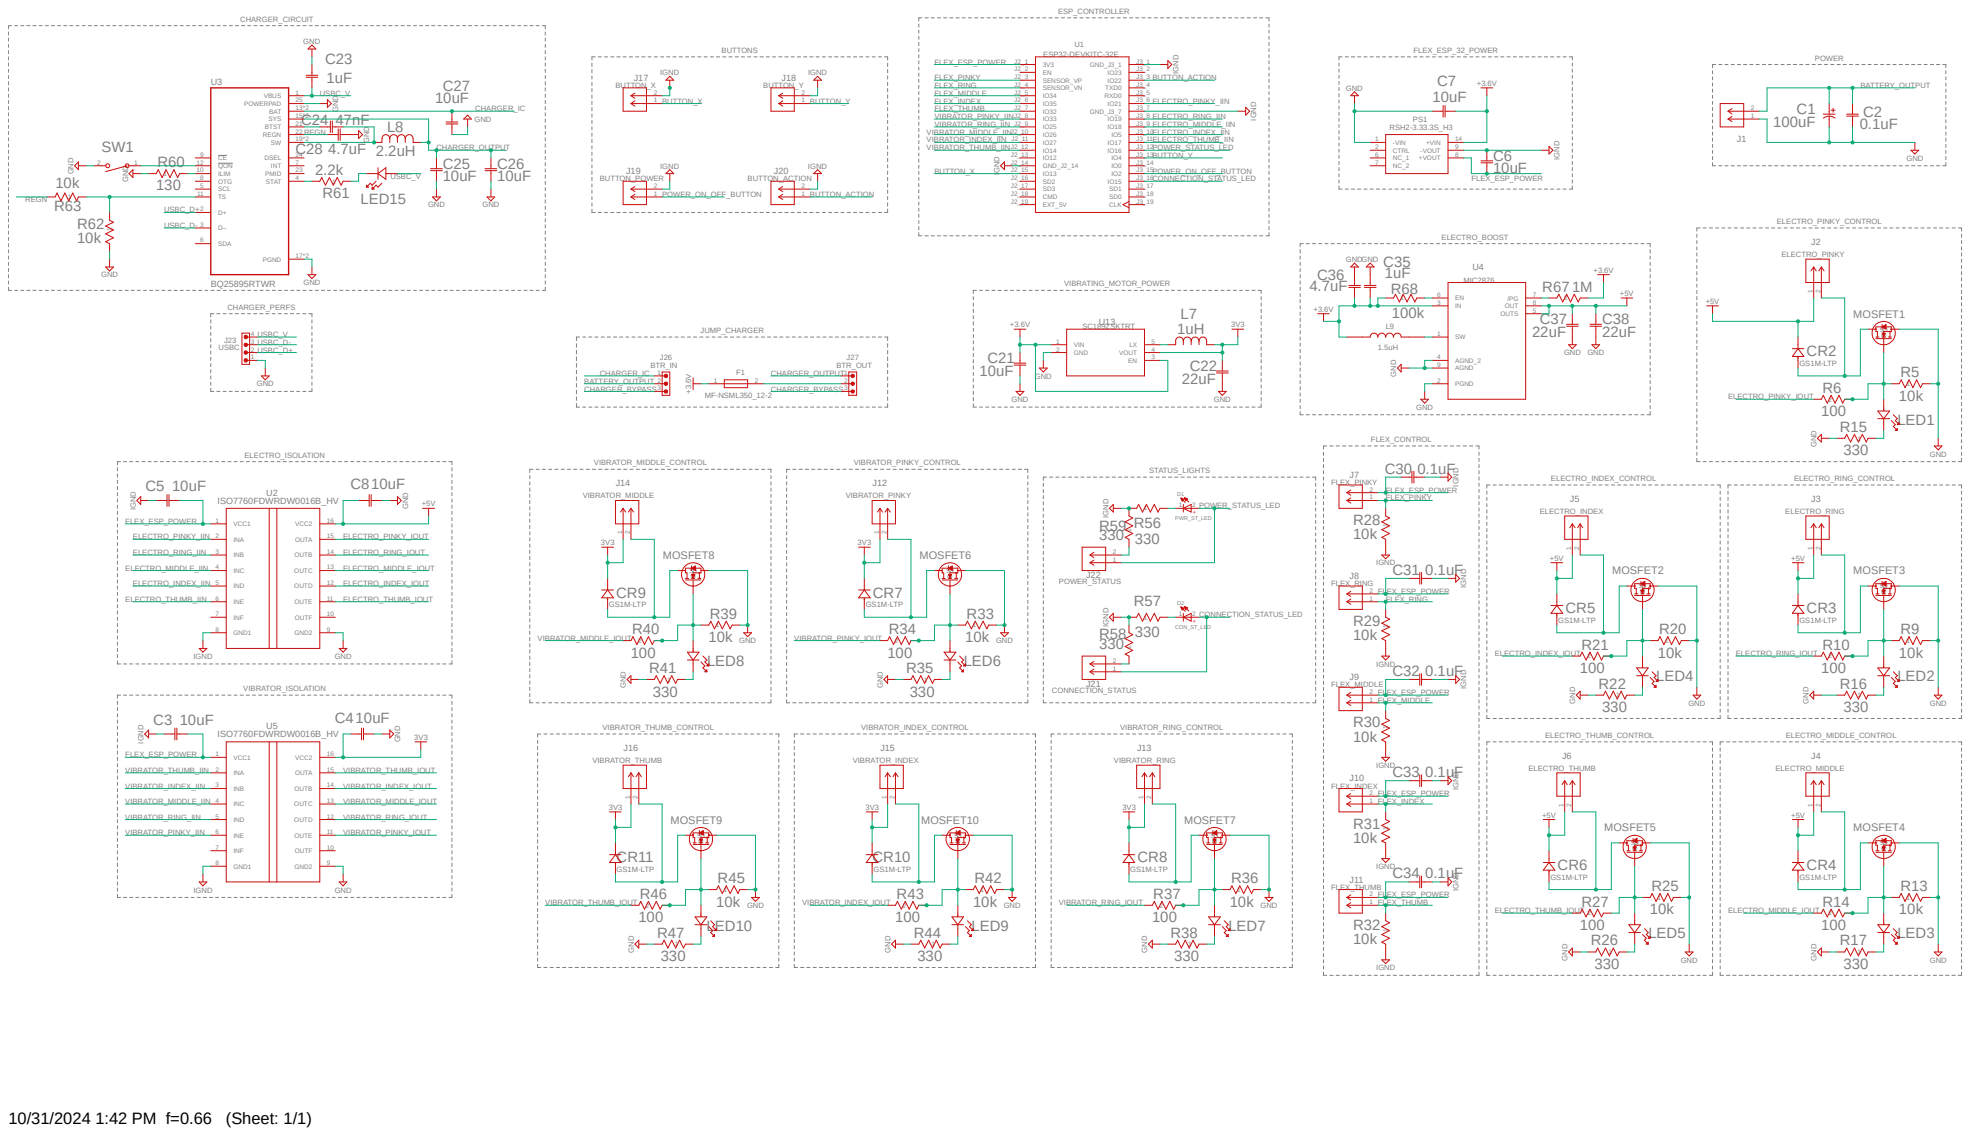
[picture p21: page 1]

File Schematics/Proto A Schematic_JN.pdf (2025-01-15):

1M

# SCHOTTKY_DIODE 100uF 0.1uF MIC2876

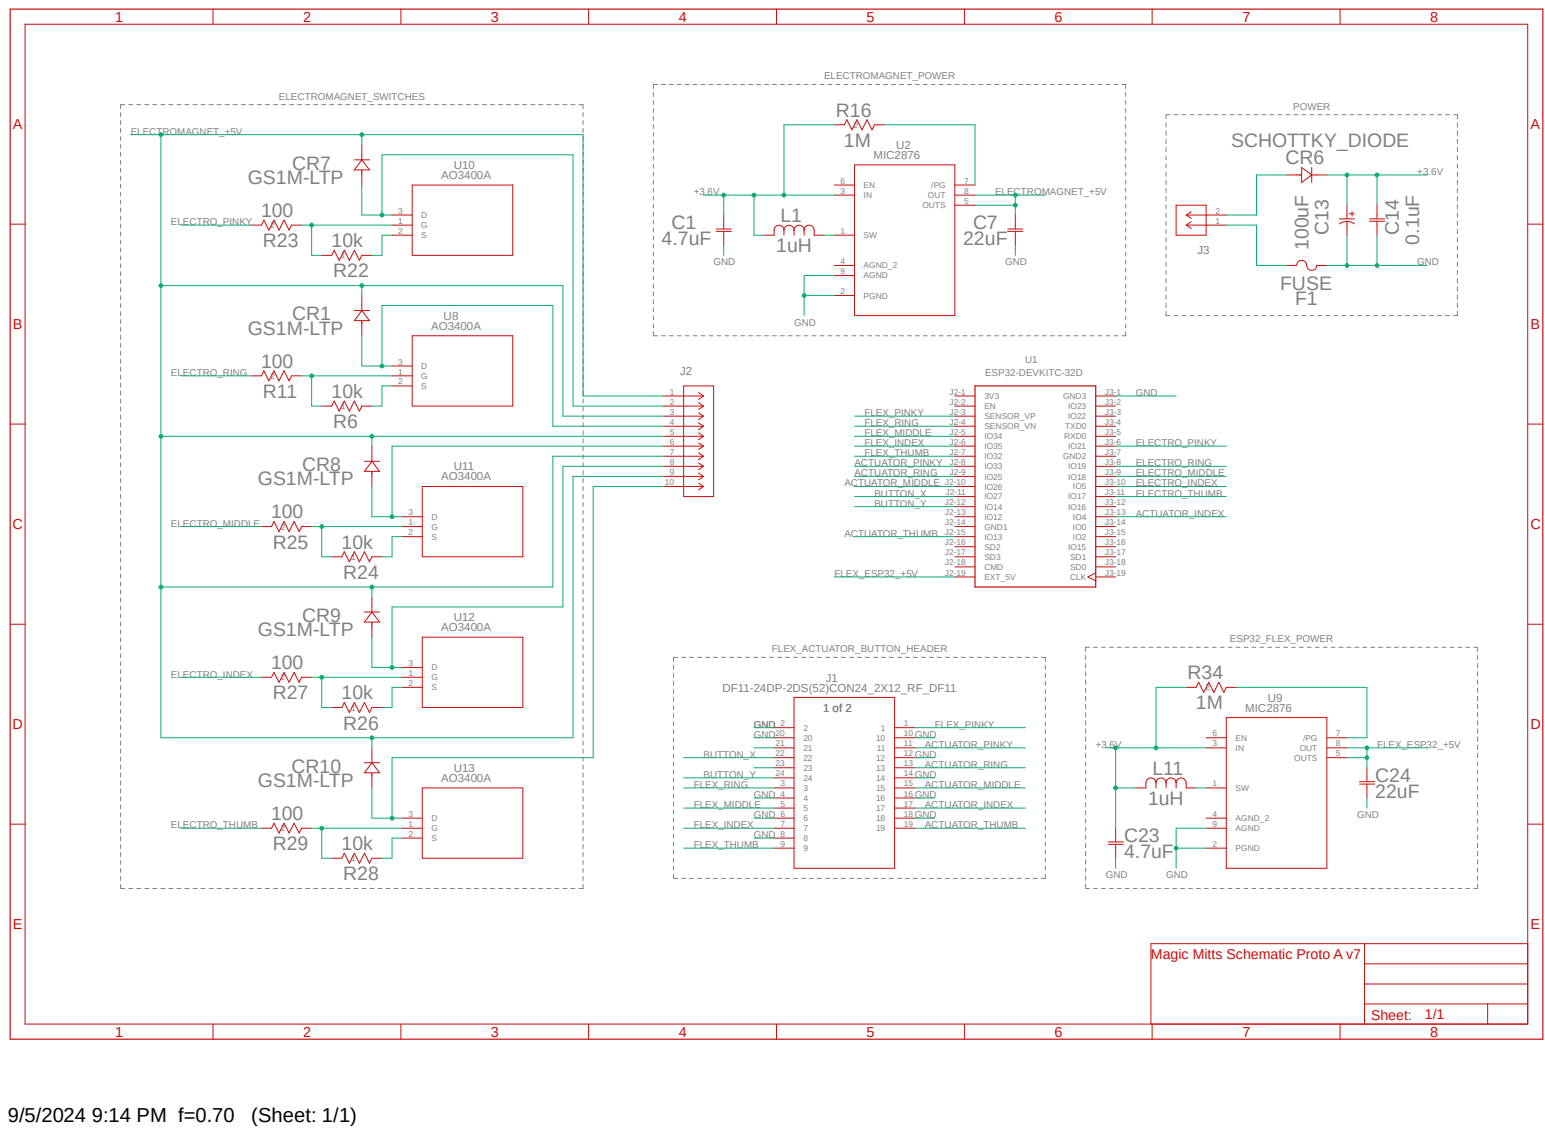
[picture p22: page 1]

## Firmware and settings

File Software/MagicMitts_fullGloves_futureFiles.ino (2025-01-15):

//This is a future file for when we receive the PCB and the full glove is installed
#include "BluetoothSerial.h"


BluetoothSerial SerialBT;

// Pin Definitions from Schematic
// Flex Sensor Inputs
const int FLEX_PINKY = 36;    // GPIO36
const int FLEX_RING = 39;     // GPIO39
const int FLEX_MIDDLE = 34;   // GPIO34
const int FLEX_INDEX = 35;    // GPIO35
const int FLEX_THUMB = 32;    // GPIO32

// PWM Outputs for Electromagnets (1kHz 50% Duty Cycle)
const int PWM_PINKY = 21;     // GPIO21
const int PWM_RING = 19;      // GPIO19
const int PWM_MIDDLE = 18;    // GPIO18
const int PWM_INDEX = 5;      // GPIO5
const int PWM_THUMB = 17;     // GPIO17

// Vibration Actuator Outputs
const int VIB_PINKY = 33;     // GPIO33
const int VIB_RING = 25;      // GPIO25
const int VIB_MIDDLE = 26;    // GPIO26
const int VIB_INDEX = 4;      // GPIO4
const int VIB_THUMB = 13;     // GPIO13

// Thresholds for flex sensors
const int thresholdIndex = 2200;
const int thresholdMiddle = 2200;
const int thresholdRing = 2100;
const int thresholdPinky = 2000;
const int thresholdThumb = 2000;

// PWM properties
const int PWM_FREQ = 1000;    // 1kHz frequency
const int PWM_RES = 8;        // 8-bit resolution (0-255)
const int PWM_CHANNELS = 5;   // Number of PWM channels needed

void setup() {
    // Initialize both Serial and Bluetooth
    Serial.begin(9600);
    SerialBT.begin("ESP32_MagicMitts");
    
    // Configure ADC for flex sensors
    analogSetWidth(12);  // 12-bit ADC resolution
    
    // Configure PWM channels for electromagnets
    ledcSetup(0, PWM_FREQ, PWM_RES);  // Channel 0 - Pinky
    ledcSetup(1, PWM_FREQ, PWM_RES);  // Channel 1 - Ring
    ledcSetup(2, PWM_FREQ, PWM_RES);  // Channel 2 - Middle
    ledcSetup(3, PWM_FREQ, PWM_RES);  // Channel 3 - Index
    ledcSetup(4, PWM_FREQ, PWM_RES);  // Channel 4 - Thumb
    
    // Attach PWM channels to GPIO pins
    ledcAttachPin(PWM_PINKY, 0);
    ledcAttachPin(PWM_RING, 1);
    ledcAttachPin(PWM_MIDDLE, 2);
    ledcAttachPin(PWM_INDEX, 3);
    ledcAttachPin(PWM_THUMB, 4);
    
    // Setup vibration actuator pins
    pinMode(VIB_PINKY, OUTPUT);
    pinMode(VIB_RING, OUTPUT);
    pinMode(VIB_MIDDLE, OUTPUT);
    pinMode(VIB_INDEX, OUTPUT);
    pinMode(VIB_THUMB, OUTPUT);

    Serial.println("System Ready. Sending data in CSV format.");
    SerialBT.println("ESP32 Glove Bluetooth Started.");
}
void loop() {
    // Read flex sensors
    int indexFlex = analogRead(FLEX_INDEX);
    int middleFlex = analogRead(FLEX_MIDDLE);
    int ringFlex = analogRead(FLEX_RING);
    int pinkyFlex = analogRead(FLEX_PINKY);
    int thumbFlex = analogRead(FLEX_THUMB);
    
    // Send values over both Serial and Bluetooth
    String dataString = String(indexFlex) + "," + 
                       String(middleFlex) + "," + 
                       String(ringFlex) + "," + 
                       String(pinkyFlex) + "," + 
                       String(thumbFlex);
    
    Serial.println(dataString);
    SerialBT.println(dataString);

    // Check for commands from both Serial and Bluetooth
    checkCommands(Serial);
    checkCommands(SerialBT);
    
    delay(20); // 50Hz update rate
}

void checkCommands(Stream &port) {
    if (port.available()) {
        String command = port.readStringUntil('\n');
        handleCommand(command);
    }
}

void handleCommand(String command) {
    // Match commands from GrabDetector.cs in unity - to receive
    if (command.startsWith("thumb_haptic")) {
        digitalWrite(VIB_THUMB, HIGH);
        delay(50);
        digitalWrite(VIB_THUMB, LOW);
    }
    else if (command.startsWith("index_haptic")) {
        digitalWrite(VIB_INDEX, HIGH);
        delay(50);
        digitalWrite(VIB_INDEX, LOW);
    }
    else if (command.startsWith("middle_haptic")) {
        digitalWrite(VIB_MIDDLE, HIGH);
        delay(50);
        digitalWrite(VIB_MIDDLE, LOW);
    }
    else if (command.startsWith("ring_haptic")) {
        digitalWrite(VIB_RING, HIGH);
        delay(50);
        digitalWrite(VIB_RING, LOW);
    }
    else if (command.startsWith("pinky_haptic")) {
        digitalWrite(VIB_PINKY, HIGH);
        delay(50);
        digitalWrite(VIB_PINKY, LOW);
    }
    // Brake commands
    else if (command.startsWith("brake_thumb")) ledcWrite(4, 255);
    else if (command.startsWith("brake_index")) ledcWrite(3, 255);
    else if (command.startsWith("brake_middle")) ledcWrite(2, 255);
    else if (command.startsWith("brake_ring")) ledcWrite(1, 255);
    else if (command.startsWith("brake_pinky")) ledcWrite(0, 255);
    // Release command
    else if (command.startsWith("release")) {
        // Turn off all electromagnets
        for(int i = 0; i < PWM_CHANNELS; i++) {
            ledcWrite(i, 0);
        }
        // Turn off all vibration actuators
        digitalWrite(VIB_THUMB, LOW);
        digitalWrite(VIB_INDEX, LOW);
        digitalWrite(VIB_MIDDLE, LOW);
        digitalWrite(VIB_RING, LOW);
        digitalWrite(VIB_PINKY, LOW);
    }
    // General buzz command
    else if (command.startsWith("buzz")) {
        // Activate all vibration actuators briefly
        digitalWrite(VIB_THUMB, HIGH);
        digitalWrite(VIB_INDEX, HIGH);
        digitalWrite(VIB_MIDDLE, HIGH);
        digitalWrite(VIB_RING, HIGH);
        digitalWrite(VIB_PINKY, HIGH);
        delay(50);
        digitalWrite(VIB_THUMB, LOW);
        digitalWrite(VIB_INDEX, LOW);
        digitalWrite(VIB_MIDDLE, LOW);
        digitalWrite(VIB_RING, LOW);
        digitalWrite(VIB_PINKY, LOW);
    }
}

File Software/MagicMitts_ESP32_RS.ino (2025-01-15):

#include "BluetoothSerial.h" 


BluetoothSerial SerialBT;

// Analog input pin for flex sensor
const int flexIndex = 34; 
const int flexMiddle = 35;
const int flexRing = 32;
const int flexPinky = 33;
const int flexThumb = 25;

#define BTN_PIN 13  // Input pin for the button
#define MOT_PIN 12  // Output pin for the motor

// Thresholds for each finger (can be tuned based on sensor range)
const int thresholdIndex = 2200;
const int thresholdMiddle = 2200;
const int thresholdRing = 2100;
const int thresholdPinky = 2000;
const int thresholdThumb = 2000;

void setup() {
  Serial.begin(9600);  // Initialize serial communication for Unity
  SerialBT.begin("ESP32_MagicMitts");  // Bluetooth device name
  pinMode(BTN_PIN, INPUT);
  pinMode(MOT_PIN, OUTPUT);  // Set actuator pin as output
  digitalWrite(MOT_PIN, LOW);  // motor is off initially

  Serial.println("System Ready. Sending data in CSV format.");
  SerialBT.println("ESP32 Glove Bluetooth Started.");
}

void loop() {

  // Read sensor values from all flex sensors
  int flexValue1 = analogRead(flexIndex);  // Index finger
  int flexValue2 = analogRead(flexMiddle);  // Middle finger
  int flexValue3 = analogRead(flexRing);    // Ring finger
  int flexValue4 = analogRead(flexPinky);   // Pinky finger
  int flexValue5 = analogRead(flexThumb);   // Thumb

  // Send values over serial as CSV (for Unity)
  Serial.print(flexValue1); Serial.print(",");
  Serial.print(flexValue2); Serial.print(",");
  Serial.print(flexValue3); Serial.print(",");
  Serial.print(flexValue4); Serial.print(",");
  Serial.println(flexValue5);  // Print newline at the end

    // Send values over Bluetooth Serial
  SerialBT.print(flexValue1); SerialBT.print(",");
  SerialBT.print(flexValue2); SerialBT.print(",");
  SerialBT.print(flexValue3); SerialBT.print(",");
  SerialBT.print(flexValue4); SerialBT.print(",");
  SerialBT.println(flexValue5);

  // Check if the button is pressed
  if (digitalRead(BTN_PIN) == HIGH) {
    activateMotor();  
  }

  if (Serial.available() > 0) {
    String command = Serial.readStringUntil('\n');
    if (command == "buzz") {  // add to haptic buzz 
      activateMotor(); 
    }
  }
  if (SerialBT.available() > 0) {
    String command = SerialBT.readStringUntil('\n');
    if (command == "buzz") {  // add to haptic buzz 
      activateMotor(); 
    }
  }

  delay(10);  // Stability delay
}

// Function to turn on the haptic motor for feedback
void activateMotor() {
  digitalWrite(MOT_PIN, HIGH);  
  delay(100);                   
  digitalWrite(MOT_PIN, LOW);  
  // delay(300); 
}

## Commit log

2025-01-15 Adding software files via upload
    Pseudo code and final code samples for working gloves
2025-01-15 Feat: Adding all CAD Files and schematics
    [BN - BP_BOTTOM A.STL, BN - BP_BOTTOM B.STL, BN - BP_LID A.STL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]
